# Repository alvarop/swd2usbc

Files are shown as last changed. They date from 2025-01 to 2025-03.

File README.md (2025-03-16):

# SWD2USBC Project

Have you ever wanted to debug your device over USB-C? Sometimes there's not enough room for a JTAG/SWD connector, or even [Tag-Connect](https://www.tag-connect.com/) pads!

For history and all of the details, check out [my detailed write up here](https://alvarop.com/2025/03/swd-to-usbc/).

## SWD2USBC
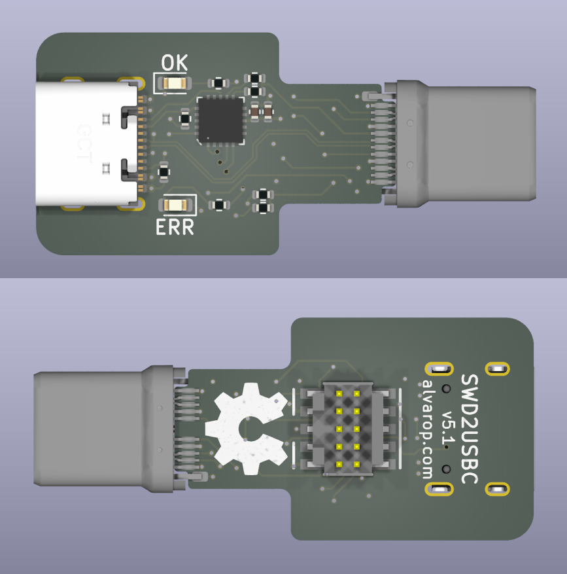
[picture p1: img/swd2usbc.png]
SWD2USBC
 

Full featured adapter with Debug Accessory Mode support. Includes an ATTiny microcontroller to set the correct pull-up resistors on CC1/CC2 to provide accurate charge current to the target. Has a USB-C plug so no extra USB-C cable required

### SWD2USBC Firmware
The ATTiny firmware doesn't do much. It reads the voltage on the CC1/CC2 line that is pulled up and determines the available charge current. It then pulls up CC1 **and** CC2 to provide the charge current to the device under Debug Accessory Mode.

## SWD2USBC Basic
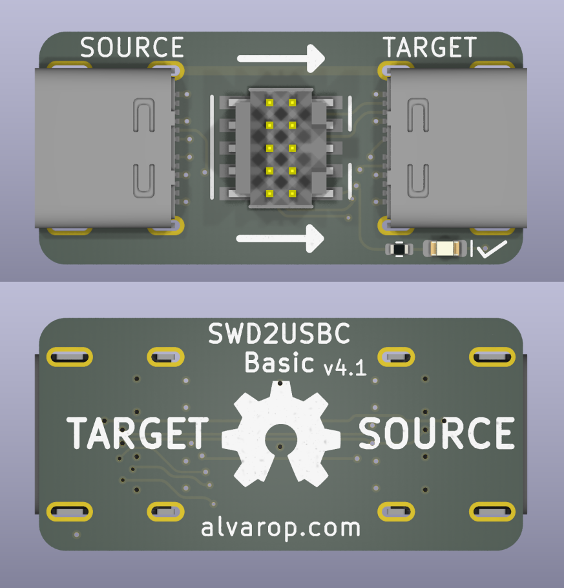
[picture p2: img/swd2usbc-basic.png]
SWD2USBC Basic
 
Simple adapter with no Debug Accessory Mode. Assumes target SWD lines wired up directly to TX1/2 as listed above. Requires USB3/Thunderbolt C to C cable to connect to target.

## Sample Target 
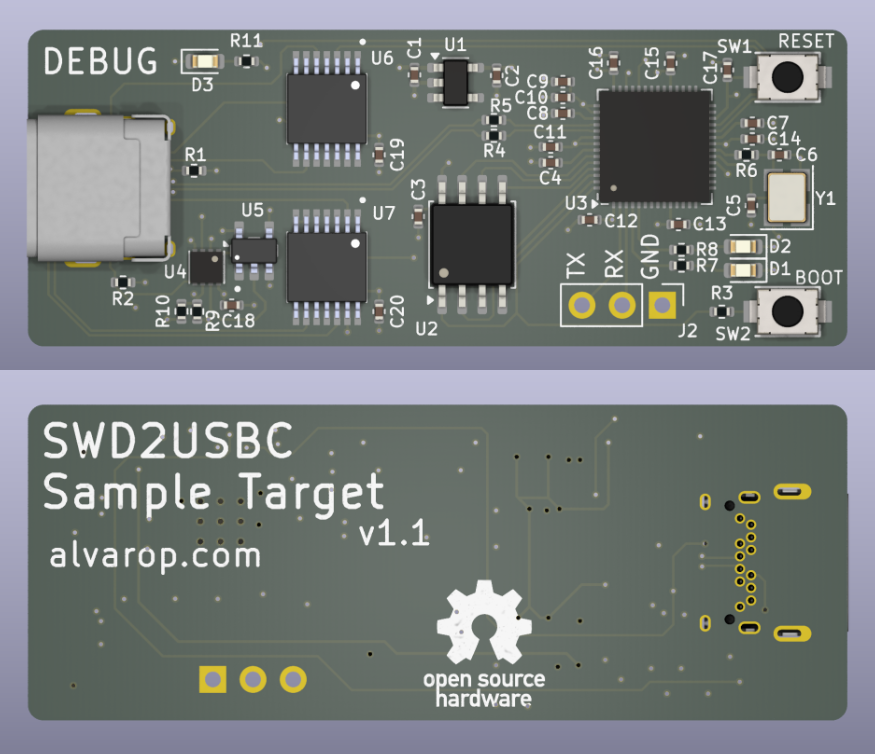
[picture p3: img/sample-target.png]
Sample Target
 

Example target device. Fully featured with CC1/2 comparators to connect/disconnect SWD lines if Debug Accessory Mode is active. Target is an RP2040 instead of STM32 since it's easier to source.

### Sample Target Firmware
The sample target firmware does basic USB charge detection using the CC lines. When the Debug Accessory Mode is enabled, both CC1/CC2 are used, otherwise, the single CC line is used. There's an LED (D3) which lights up when Debug Accessory Mode is enabled.

The charge current is printed out over UART, but it is also displayed using the two LEDs. The blink patterns are:
* **500mA** - LED1 (D1) blinks 
* **1500mA** - LED2 (D2) blinks 
* **3000mA** - Both LED1 (D1) and LED2 (D2) blink at the same time
* **Other/Error** - Both LED1 (D1) and LED2 (D2) alternating blink

## Sample Target Basic
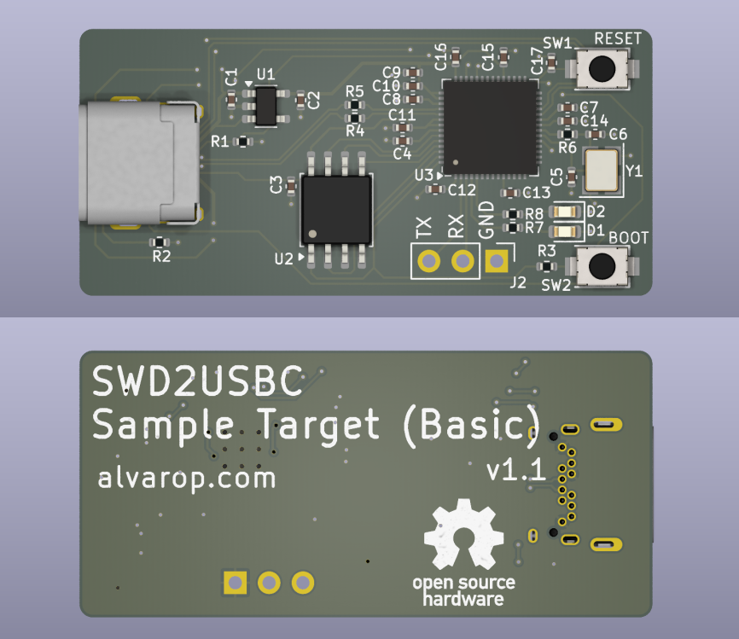
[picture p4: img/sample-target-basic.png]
Sample Target Basic
 

Basic example target. Similar to the sample target above, but does not include any comparators/switches. SWD lines are directly connected to the USB-C connector.

## SWD2USBC Programmer
Simple adapter PCB to connect the AVRISP V2 connector to USB-C to program the ATTiny in the SWD2USBC device.

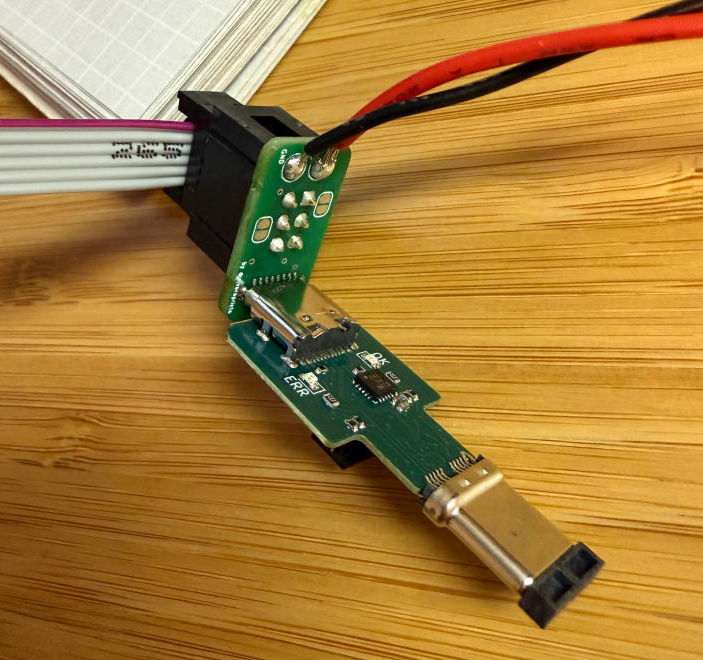
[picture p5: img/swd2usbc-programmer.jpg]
SWD2USBC Programmer


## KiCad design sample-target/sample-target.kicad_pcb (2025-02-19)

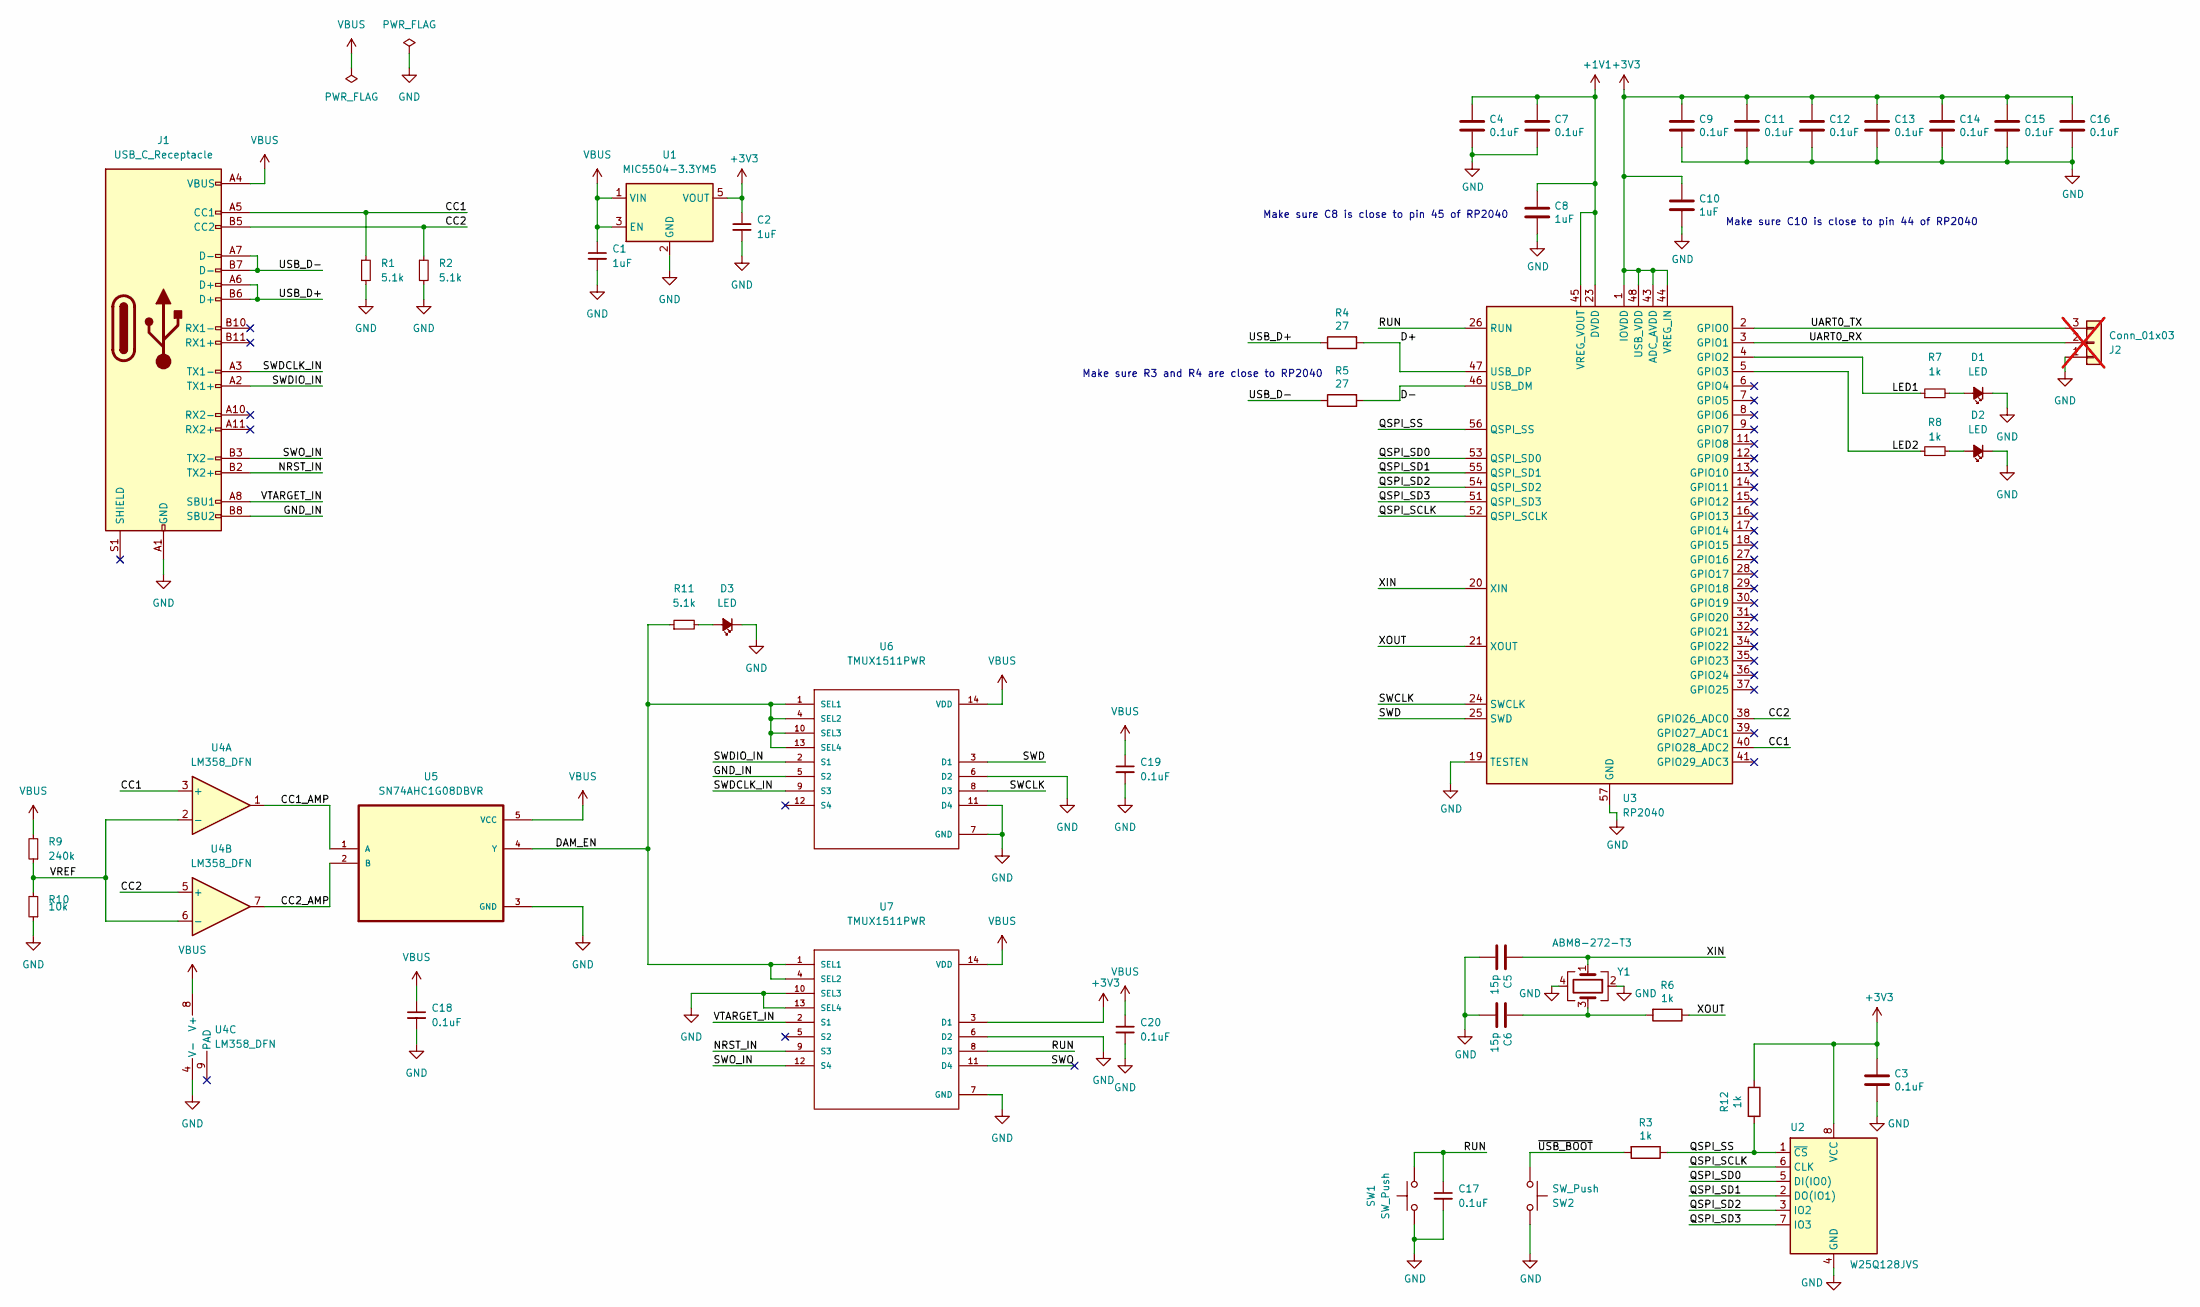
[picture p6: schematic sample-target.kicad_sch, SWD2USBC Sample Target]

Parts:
C1, C2, C8, C10: 1uF; C_0402_1005Metric; LCSC C52923
C3, C4, C7, C9, C11, C12, C13, C14, C15, C16, C17, C18, C19, C20: 0.1uF; C_0402_1005Metric; MPN CL05B104KB54PNC; LCSC C307331
C5, C6: 15p; C_0402_1005Metric; LCSC C106997
D1, D2, D3: LED; LED_0603_1608Metric; LCSC C72038
J1: USB_C_Receptacle; UT11113-11602-7H; MPN UT11113-11602-7H; LCSC C2761408
J2: Conn_01x03; PinHeader_1x03_P2.54mm_Vertical; not fitted
R1, R2, R11: 5.1k; R_0402_1005Metric; LCSC C105872
R3, R6, R7, R8, R12: 1k; R_0402_1005Metric; LCSC C4190
R4, R5: 27; R_0402_1005Metric; LCSC C137890
R9: 240k; R_0402_1005Metric; LCSC C138029
R10: 10k; R_0402_1005Metric; LCSC C25744
SW1, SW2: SW_Push; SW-SMD_L3.9-W3.0-P4.45; MPN SKRKAEE020; LCSC C115357
U1: MIC5504-3.3YM5; SOT-23-5; MPN MIC5504-3.3YM5-TR; LCSC C41348078
U2: W25Q128JVS; SOIC-8_5.23x5.23mm_P1.27mm; MPN W25Q128JVS; LCSC C97521
U3: RP2040; QFN-56-1EP_7x7mm_P0.4mm_EP3.2x3.2mm; MPN RP2040; LCSC C2040
U4: LM358_DFN; DFN-8-1EP_2x2mm_P0.5mm_EP1.05x1.75mm; MPN LM358QT; LCSC C2649392
U5: SN74AHC1G08DBVR; SOT95P280X145-5N; MPN SN74AHC1G08DBVR; LCSC C7467
U6, U7: TMUX1511PWR; SOP65P640X120-14N; MPN TMUX1511PWR; LCSC C2866750
Y1: ABM8-272-T3; Crystal_SMD_3225-4Pin_3.2x2.5mm; MPN ABM8-272-T3; LCSC C20625731

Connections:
+1V1: C4.1, C7.1, C8.1, U3.23 (DVDD), U3.45 (VREG_VOUT), U3.50 (DVDD)
+3V3: C2.1, C3.1, C9.1, C10.1, C11.1, C12.1, C13.1, C14.1, C15.1, C16.1, R12.1, U1.5 (VOUT), U2.8 (VCC), U3.1 (IOVDD), U3.10 (IOVDD), U3.22 (IOVDD), U3.33 (IOVDD), U3.42 (IOVDD), U3.43 (ADC_AVDD), U3.44 (VREG_IN), U3.48 (USB_VDD), U3.49 (IOVDD), U7.3 (D1)
/CC1: J1.A5 (CC1), R1.1, U3.40 (GPIO28_ADC2), U4.3 (+)
/CC1_AMP: U4.1, U5.1 (A)
/CC2: J1.B5 (CC2), R2.1, U3.38 (GPIO26_ADC0), U4.5 (+)
/CC2_AMP: U4.7, U5.2 (B)
/D+: R4.2, U3.47 (USB_DP)
/D-: R5.2, U3.46 (USB_DM)
/DAM_EN: R11.1, U5.4 (Y), U6.1 (SEL1), U6.4 (SEL2), U6.10 (SEL3), U6.13 (SEL4), U7.1 (SEL1), U7.4 (SEL2)
/GND_IN: J1.B8 (SBU2), U6.5 (S2)
/LED1: R7.1, U3.4 (GPIO2)
/LED2: R8.1, U3.5 (GPIO3)
/NRST_IN: J1.B2 (TX2+), U7.9 (S3)
/QSPI_SCLK: U2.6 (CLK), U3.52 (QSPI_SCLK)
/QSPI_SD0: U2.5 (DI(IO0)), U3.53 (QSPI_SD0)
/QSPI_SD1: U2.2 (DO(IO1)), U3.55 (QSPI_SD1)
/QSPI_SD2: U2.3 (IO2), U3.54 (QSPI_SD2)
/QSPI_SD3: U2.7 (IO3), U3.51 (QSPI_SD3)
/QSPI_SS: R3.1, R12.2, U2.1 (~CS), U3.56 (QSPI_SS)
/RUN: C17.1, SW1.2, U3.26 (RUN), U7.8 (D3)
/SWCLK: U3.24 (SWCLK), U6.8 (D3)
/SWD: U3.25 (SWD), U6.3 (D1)
/SWDCLK_IN: J1.A3 (TX1-), U6.9 (S3)
/SWDIO_IN: J1.A2 (TX1+), U6.2 (S1)
/SWO: U7.11 (D4)
/SWO_IN: J1.B3 (TX2-), U7.12 (S4)
/UART0_RX: J2.2, U3.3 (GPIO1)
/UART0_TX: J2.3, U3.2 (GPIO0)
/USB_D+: J1.A6 (D+), J1.B6 (D+), R4.1
/USB_D-: J1.A7 (D-), J1.B7 (D-), R5.1
/VREF: R9.1, R10.2, U4.2 (-), U4.6 (-)
/VTARGET_IN: J1.A8 (SBU1), U7.2 (S1)
/XIN: C5.1, U3.20 (XIN), Y1.1
/XOUT: R6.1, U3.21 (XOUT)
/~USB_BOOT: R3.2, SW2.2
GND: C1.2, C2.2, C3.2, C4.2, C5.2, C6.2, C7.2, C8.2, C9.2, C10.2, C11.2, C12.2, C13.2, C14.2, C15.2, C16.2, C17.2, C18.2, C19.2, C20.2, D1.1 (K), D2.1 (K), D3.1 (K), J1.A1 (GND), J1.A12 (GND), J1.B1 (GND), J1.B12 (GND), J2.1, R1.2, R2.2, R10.1, SW1.1, SW2.1, U1.2 (GND), U2.4 (GND), U3.19 (TESTEN), U3.57 (GND), U4.4 (V-), U5.3 (GND), U6.6 (D2), U6.7 (GND), U6.11 (D4), U7.6 (D2), U7.7 (GND), U7.10 (SEL3), U7.13 (SEL4), Y1.2, Y1.4
unnamed: C6.1, R6.2, Y1.3
unnamed: D1.2 (A), R7.2
unnamed: D2.2 (A), R8.2
unnamed: D3.2 (A), R11.2
VBUS: C1.1, C18.1, C19.1, C20.1, J1.A4 (VBUS), J1.A9 (VBUS), J1.B4 (VBUS), J1.B9 (VBUS), R9.2, U1.1 (VIN), U1.3 (EN), U4.8 (V+), U5.5 (VCC), U6.14 (VDD), U7.14 (VDD)

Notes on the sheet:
Make sure C10 is close to pin 44 of RP2040
Make sure C8 is close to pin 45 of RP2040
Make sure R3 and R4 are close to RP2040

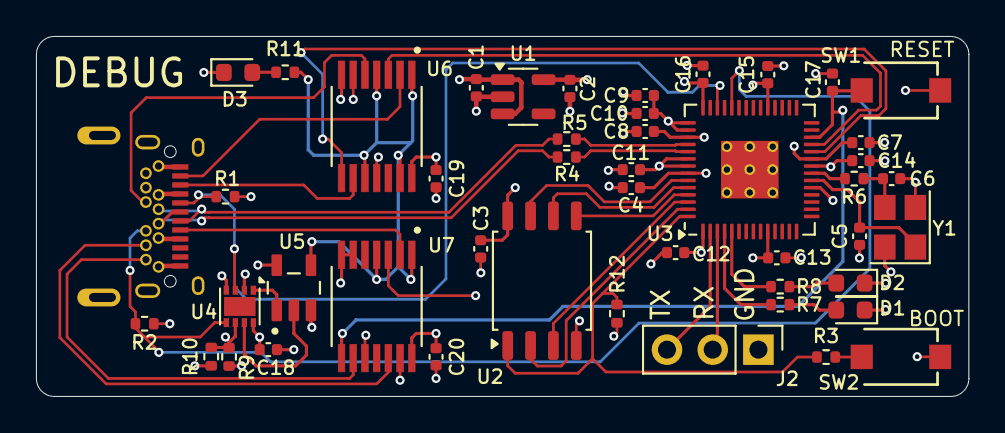
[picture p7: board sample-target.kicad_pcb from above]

Board: 4 copper layers, 51.8 x 20.0 mm, 47 parts (0 on the bottom side), 40 nets.

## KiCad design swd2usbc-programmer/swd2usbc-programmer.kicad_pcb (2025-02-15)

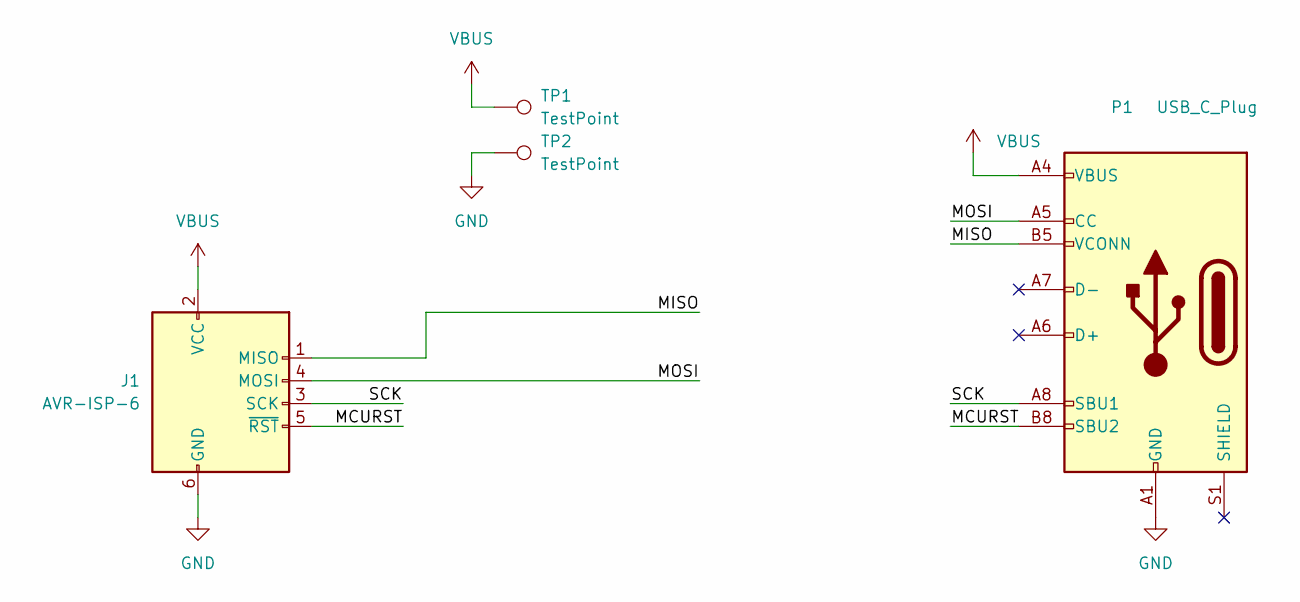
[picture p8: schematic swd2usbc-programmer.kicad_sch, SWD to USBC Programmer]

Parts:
J1: AVR-ISP-6; IDC-Header_2x03_P2.54mm_Vertical; MPN 30306-6002HB
P1: USB_C_Plug; TYPE-C-31-G-06; MPN TYPE-C-31-G-06
TP1, TP2: TestPoint; TestPoint_Pad_D2.5mm

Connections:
/MCURST: J1.5 (~RST), P1.B8 (SBU2)
/MISO: J1.1 (MISO), P1.B5 (VCONN)
/MOSI: J1.4 (MOSI), P1.A5 (CC)
/SCK: J1.3 (SCK), P1.A8 (SBU1)
GND: J1.6 (GND), P1.A1 (GND), P1.A12 (GND), P1.B1 (GND), P1.B12 (GND), TP2.1
VBUS: J1.2 (VCC), P1.A4 (VBUS), P1.A9 (VBUS), P1.B4 (VBUS), P1.B9 (VBUS), TP1.1

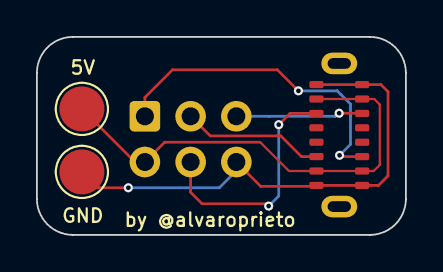
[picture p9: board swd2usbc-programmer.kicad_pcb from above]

Board: 2 copper layers, 20.5 x 11.0 mm, 4 parts (1 on the bottom side), 6 nets.

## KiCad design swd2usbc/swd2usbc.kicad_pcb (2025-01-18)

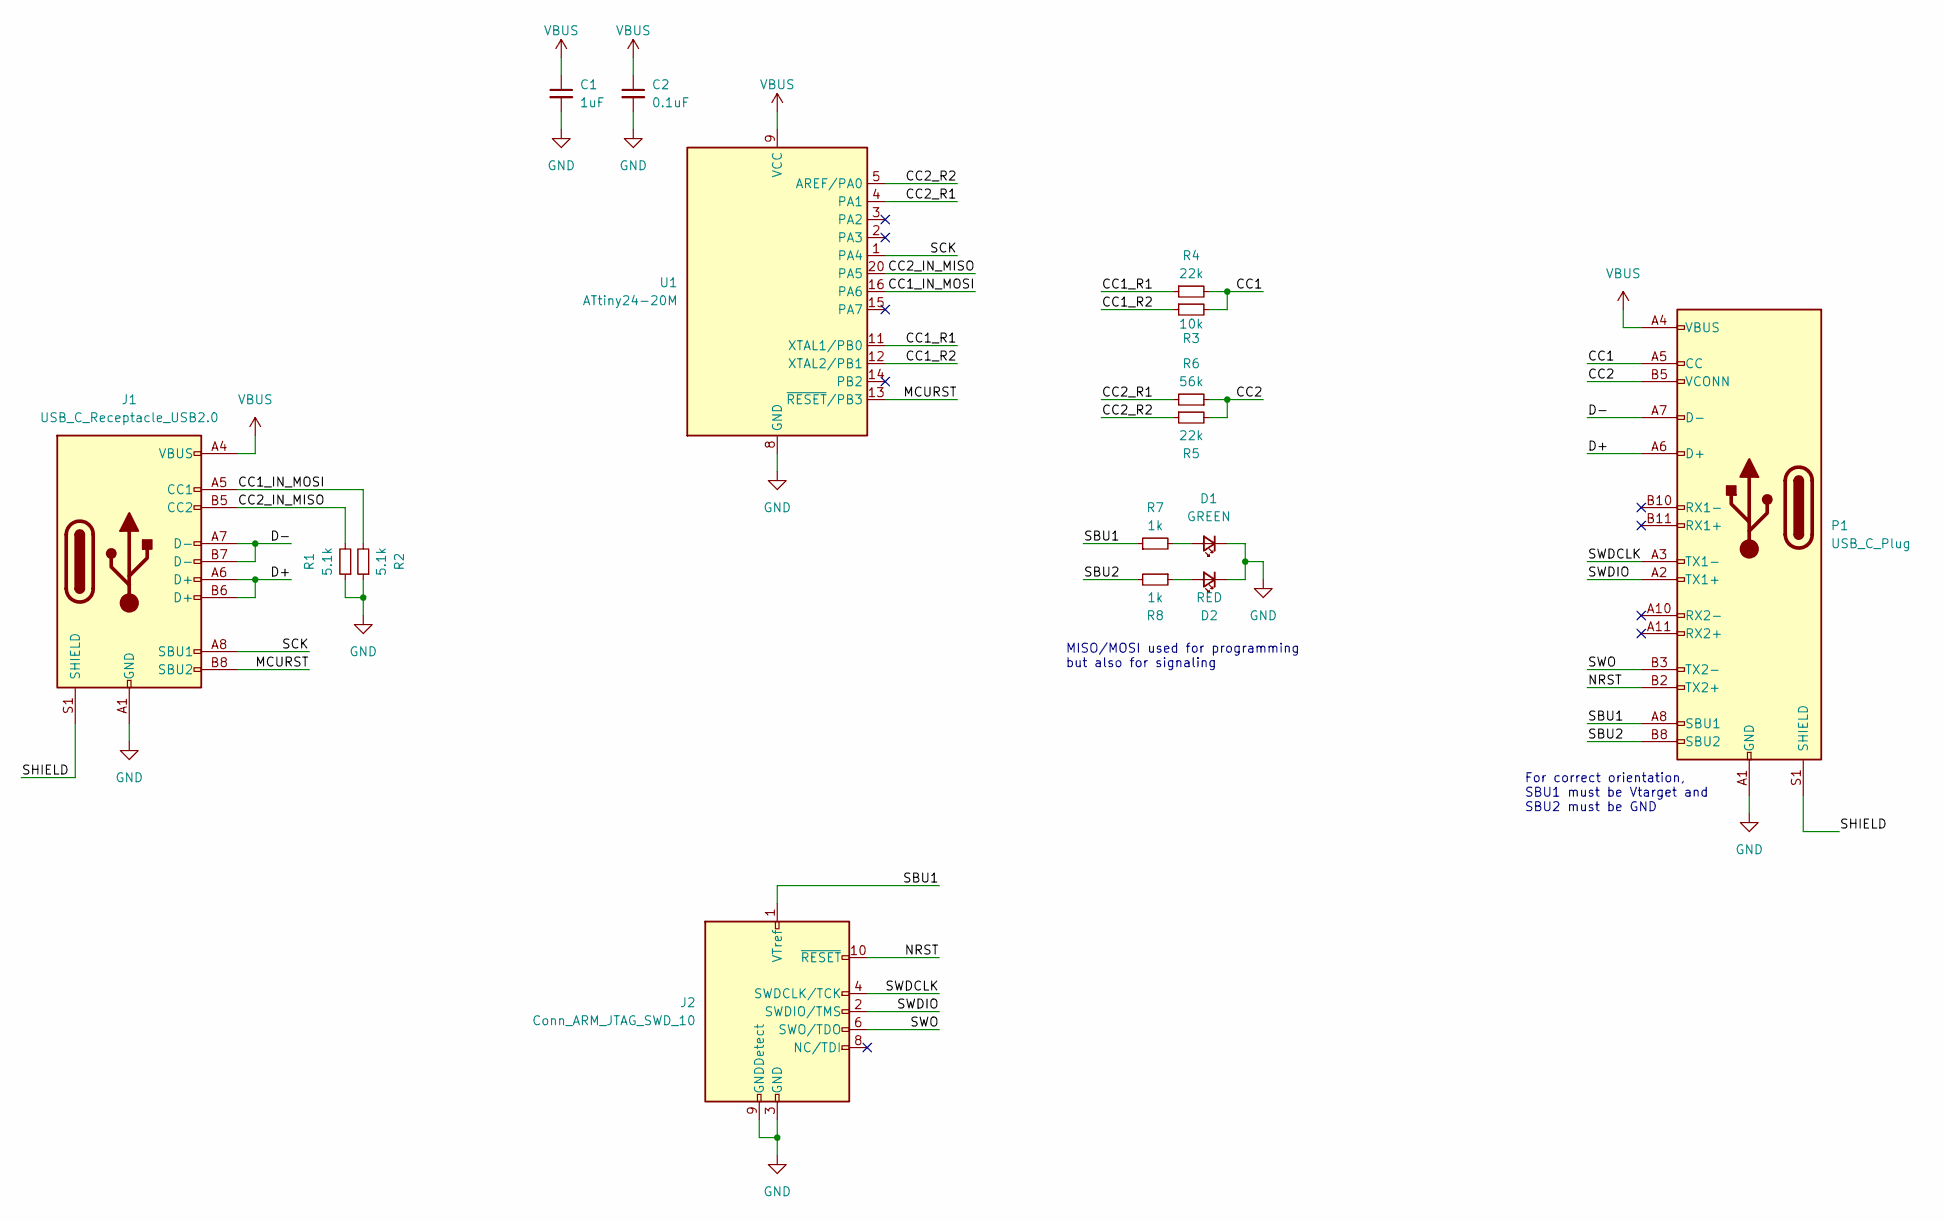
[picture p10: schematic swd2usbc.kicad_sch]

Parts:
C1: 1uF; C_0402_1005Metric; MPN CL05A105KO5NNNC; LCSC C52923
C2: 0.1uF; C_0402_1005Metric; MPN CL05B104KO5NNNC; LCSC C307331
D1: GREEN; LED_0603_1608Metric; MPN SML-D12M8WT86; LCSC C965804
D2: RED; LED_0603_1608Metric; MPN SML-D12U1WT86; LCSC C2286
J1: USB_C_Receptacle_USB2.0; USB4105-GF-A; MPN USB4105-GF-A; LCSC C136423
J2: Conn_ARM_JTAG_SWD_10; SAMTEC_FTSH-105-01-F-DV-P-TR; MPN FTSH-105-01-F-DV-K; LCSC C2935458
P1: USB_C_Plug; MOLEX_1054440011; MPN 1054440011; LCSC C561769
R1, R2: 5.1k; R_0402_1005Metric; MPN RC0402FR-075K1L; LCSC C105872
R3: 10k; R_0402_1005Metric; MPN RC0402FR-0710KL; LCSC C25744
R4, R5: 22k; R_0402_1005Metric; MPN RC0402FR-0722KL; LCSC C25768
R6: 56k; R_0402_1005Metric; MPN RC0402FR-0756KL; LCSC C25796
R7, R8: 1k; R_0402_1005Metric; MPN RC0402FR-071KL; LCSC C4190
U1: ATtiny24-20M; ATTINY24A-MMH; MPN ATTINY24A-MMH; LCSC C617902

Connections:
/CC1: P1.A5 (CC), R3.2, R4.2
/CC1_IN_MOSI: J1.A5 (CC1), R2.2, U1.16 (PA6)
/CC1_R1: R4.1, U1.11 (XTAL1/PB0)
/CC1_R2: R3.1, U1.12 (XTAL2/PB1)
/CC2: P1.B5 (VCONN), R5.2, R6.1
/CC2_IN_MISO: J1.B5 (CC2), R1.2, U1.20 (PA5)
/CC2_R1: R6.2, U1.4 (PA1)
/CC2_R2: R5.1, U1.5 (AREF/PA0)
/D+: J1.A6 (D+), J1.B6 (D+), P1.A6 (D+)
/D-: J1.A7 (D-), J1.B7 (D-), P1.A7 (D-)
/MCURST: J1.B8 (SBU2), U1.13 (~RESET/PB3)
/NRST: J2.10 (~RESET), P1.B2 (TX2+)
/SBU1: J2.1 (VTref), P1.A8 (SBU1), R7.1
/SBU2: P1.B8 (SBU2), R8.2
/SCK: J1.A8 (SBU1), U1.1 (PA4)
/SHIELD: J1.S1 (SHIELD), P1.S1 (SHIELD)
/SWDCLK: J2.4 (SWDCLK/TCK), P1.A3 (TX1-)
/SWDIO: J2.2 (SWDIO/TMS), P1.A2 (TX1+)
/SWO: J2.6 (SWO/TDO), P1.B3 (TX2-)
GND: C1.2, C2.2, D1.1 (K), D2.1 (K), J1.A1 (GND), J1.A12 (GND), J1.B1 (GND), J1.B12 (GND), J2.3 (GND), J2.5 (GND), J2.9 (GNDDetect), P1.A1 (GND), P1.A12 (GND), P1.B1 (GND), P1.B12 (GND), R1.1, R2.1, U1.8 (GND), U1.21 (GND)
unnamed: D1.2 (A), R7.2
unnamed: D2.2 (A), R8.1
VBUS: C1.1, C2.1, J1.A4 (VBUS), J1.A9 (VBUS), J1.B4 (VBUS), J1.B9 (VBUS), P1.A4 (VBUS), P1.A9 (VBUS), P1.B4 (VBUS), P1.B9 (VBUS), U1.9 (VCC)

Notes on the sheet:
MISO/MOSI used for programming but also for signaling
For correct orientation, SBU1 must be Vtarget and SBU2 must be GND

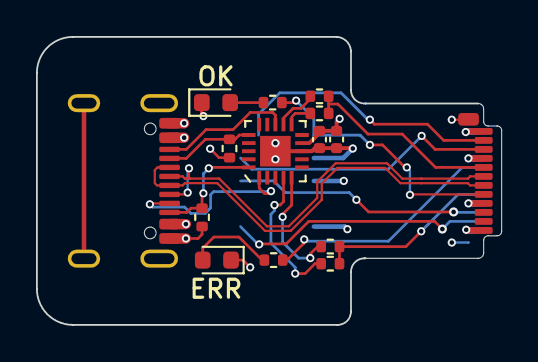
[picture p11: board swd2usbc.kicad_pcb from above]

Board: 4 copper layers, 25.8 x 16.0 mm, 16 parts (1 on the bottom side), 23 nets.

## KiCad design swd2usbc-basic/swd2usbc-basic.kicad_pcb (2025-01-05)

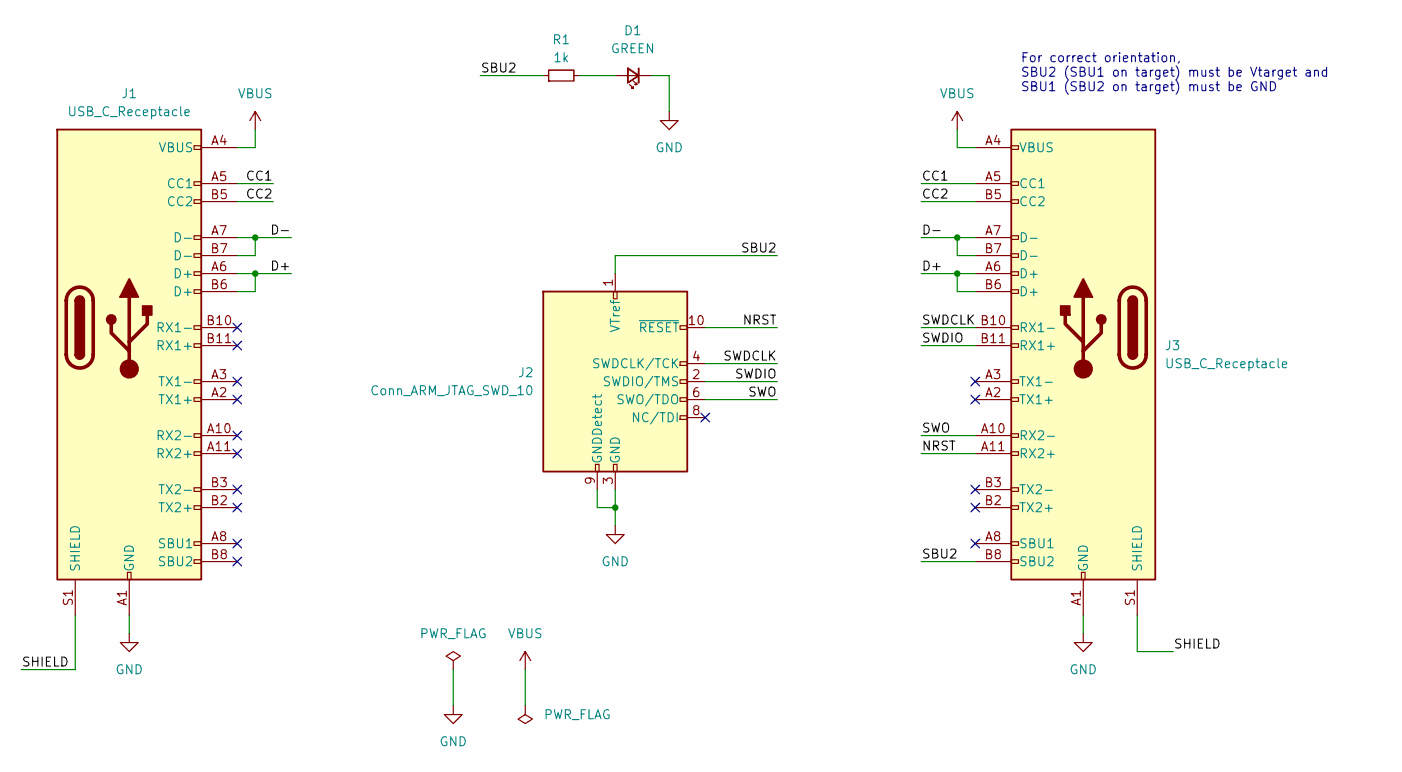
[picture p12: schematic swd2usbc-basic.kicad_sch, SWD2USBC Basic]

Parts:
D1: GREEN; LED_0603_1608Metric; MPN SML-D12M8WT86; LCSC C965804
J1, J3: USB_C_Receptacle; MOLEX-1054500101; MPN 1054500101; LCSC C134092
J2: Conn_ARM_JTAG_SWD_10; SAMTEC_FTSH-105-01-F-DV-P-TR; MPN FTSH-105-01-F-DV-K-P-TR; LCSC C19191729
R1: 1k; R_0402_1005Metric; MPN RC0402FR-071KL; LCSC C25744

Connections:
/CC1: J1.A5 (CC1), J3.A5 (CC1)
/CC2: J1.B5 (CC2), J3.B5 (CC2)
/D+: J1.A6 (D+), J1.B6 (D+), J3.A6 (D+), J3.B6 (D+)
/D-: J1.A7 (D-), J1.B7 (D-), J3.A7 (D-), J3.B7 (D-)
/NRST: J2.10 (~RESET), J3.A11 (RX2+)
/SBU2: J2.1 (VTref), J3.B8 (SBU2), R1.1
/SHIELD: J1.S1 (SHIELD), J3.S1 (SHIELD)
/SWDCLK: J2.4 (SWDCLK/TCK), J3.B10 (RX1-)
/SWDIO: J2.2 (SWDIO/TMS), J3.B11 (RX1+)
/SWO: J2.6 (SWO/TDO), J3.A10 (RX2-)
GND: D1.1 (K), J1.A1 (GND), J1.A12 (GND), J1.B1 (GND), J1.B12 (GND), J2.3 (GND), J2.5 (GND), J2.9 (GNDDetect), J3.A1 (GND), J3.A12 (GND), J3.B1 (GND), J3.B12 (GND)
unnamed: D1.2 (A), R1.2
VBUS: J1.A4 (VBUS), J1.A9 (VBUS), J1.B4 (VBUS), J1.B9 (VBUS), J3.A4 (VBUS), J3.A9 (VBUS), J3.B4 (VBUS), J3.B9 (VBUS)

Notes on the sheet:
For correct orientation, SBU2 (SBU1 on target) must be Vtarget and SBU1 (SBU2 on target) must be GND

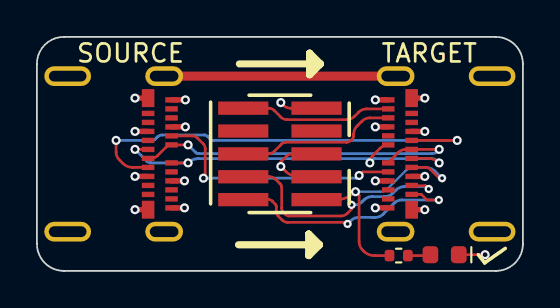
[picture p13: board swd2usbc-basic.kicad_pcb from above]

Board: 4 copper layers, 27.0 x 13.0 mm, 5 parts (0 on the bottom side), 13 nets.

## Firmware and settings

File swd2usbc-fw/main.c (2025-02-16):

#include <avr/io.h>
#include <util/delay.h>

#define MAX(X, Y) ((X) > (Y) ? (X) : (Y))

// Input CC1/CC2
#define CC1 PA6
#define CC2 PA5

// Output CC1/CC2 Rpu's
#define CC1_R2 PB1  // 10 kOhm
#define CC1_R1 PB0  // 22 kOhm
#define CC2_R2 PA0  // 22 kOhm
#define CC2_R1 PA1  // 56 kOhm

typedef enum {
  USB_500MA,
  USB_1500MA,
  USB_3000MA,
} USBCurrent_t;

// Current | CC1/CC2 In | CC1 Rpu          | CC2 Rpu
// 500mA   |    0.42V   | 10 kOhm (CC1_R2) | 22 kOhm (CC2_R2)
// 1.5A    |    0.94V   | 22 kOhm (CC1_R1) | 56 kOhm (CC2_R1)
// 3.0A    |    1.69V   | 10 kOhm (CC1_R2) | 56 kOhm (CC2_R1)

void set_usb_current(USBCurrent_t current) {
  switch (current) {
    case USB_500MA: {
      DDRB &= ~_BV(CC1_R1);
      DDRB |= _BV(CC1_R2);
      PORTB &= ~_BV(CC1_R1);
      PORTB |= _BV(CC1_R2);

      DDRA &= ~_BV(CC2_R1);
      DDRA |= _BV(CC2_R2);
      PORTA &= ~_BV(CC2_R1);
      PORTA |= _BV(CC2_R2);
      break;
    }
    case USB_1500MA: {
      DDRB &= ~_BV(CC1_R2);
      DDRB |= _BV(CC1_R1);
      PORTB &= ~_BV(CC1_R2);
      PORTB |= _BV(CC1_R1);

      DDRA &= ~_BV(CC2_R2);
      DDRA |= _BV(CC2_R1);
      PORTA &= ~_BV(CC2_R2);
      PORTA |= _BV(CC2_R1);
      break;
    }
    case USB_3000MA: {
      DDRB &= ~_BV(CC1_R1);
      DDRB |= _BV(CC1_R2);
      PORTB &= ~_BV(CC1_R1);
      PORTB |= _BV(CC1_R2);

      DDRA &= ~_BV(CC2_R2);
      DDRA |= _BV(CC2_R1);
      PORTA &= ~_BV(CC2_R2);
      PORTA |= _BV(CC2_R1);
      break;
    }
  }
}

uint16_t adc_sample_mv(uint8_t channel) {
  ADMUX = channel;
  ADCSRA |= (1 << ADSC);  // Start conversion

  // Wait for conversion to complete
  while (ADCSRA & (1 << ADSC));

  uint16_t raw_adc_val = ADC;
  uint32_t adc_mv = ((uint32_t)raw_adc_val * 5000) / 1024;

  return adc_mv;
}

// CC1/CC2 voltages for various USB C currents
#define USB_CC_MV_500MA 200
#define USB_CC_MV_1500MA 660
#define USB_CC_MV_3000MA 1230

USBCurrent_t get_cc_current(void) {
  // Read CC1/CC2 values for input current detection
  uint16_t cc1 = adc_sample_mv(CC1);
  uint16_t cc2 = adc_sample_mv(CC2);

  cc1 = MAX(cc1, cc2);

  USBCurrent_t curent;
  if (cc1 <= USB_CC_MV_1500MA) {
    curent = USB_500MA;
  } else if (cc1 <= USB_CC_MV_3000MA) {
    curent = USB_1500MA;
  } else {
    curent = USB_3000MA;
  }

  return curent;
}

int main(void) {
  // Set port B output 0 as inputs
  DDRA &= ~(_BV(CC2_R2) | _BV(CC2_R1));
  DDRB &= ~(_BV(CC1_R2) | _BV(CC1_R1));

  // Set outputs high (so they are on when switched to outputs)
  PORTA = _BV(CC2_R2) | _BV(CC2_R1);
  PORTB = _BV(CC1_R2) | _BV(CC1_R1);

  // ADC Enable with / 16 prescaler (62.5kHz)
  ADCSRA = (1 << ADEN) | 3;

  // Disable digital inputs on ADC pins
  DIDR0 |= _BV(CC1) | _BV(CC2);

  // Default to 500mA charge current to start
  set_usb_current(USB_500MA);

  while (1) {
    set_usb_current(get_cc_current());
    _delay_ms(10);
  }
  return 0;
}

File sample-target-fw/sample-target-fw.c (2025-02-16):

#include <stdio.h>

#include "hardware/adc.h"
#include "hardware/gpio.h"
#include "pico/stdlib.h"
#define LED1 (2)
#define LED2 (3)

float read_adc_v(uint8_t adc_ch) {
  const float conversion_factor = 3.3f / (1 << 12);
  adc_select_input(adc_ch);
  return (float)adc_read() * conversion_factor;
}

// Defines for voltage at each CCx charge level in normal mode
// Debug Accessory Mode uses same voltage levels but they mean different things
// USB-C Spec R2.0 - Tables 4-24 and 4-36
#define USB_CC_500MA_V 0.2
#define USB_CC_1500MA_V 0.66
#define USB_CC_3000MA_V 1.23

#define CC1_ADC_CH (2)
#define CC2_ADC_CH (0)

static uint32_t get_charge_current(bool *in_debug_mode) {
  uint32_t charge_current_ma = 0;

  float cc1 = read_adc_v(CC1_ADC_CH);
  float cc2 = read_adc_v(CC2_ADC_CH);

  // Make sure this works in both orientations
  float USB_cc_max = MAX(cc1, cc2);
  float USB_cc_min = MIN(cc1, cc2);

  // Both cc1 AND cc2 are high, use Debug Accessory Mode decoding
  // USB-C spec R2.0 Table B-2 and Table 4-36
  if ((USB_cc_max > USB_CC_500MA_V) && (USB_cc_min > USB_CC_500MA_V)) {
    if ((USB_cc_max >= USB_CC_3000MA_V) && (USB_cc_min <= USB_CC_3000MA_V) &&
        (USB_cc_min >= USB_CC_1500MA_V)) {
      charge_current_ma = 500;
    } else if ((USB_cc_max <= USB_CC_3000MA_V) &&
               (USB_cc_max >= USB_CC_1500MA_V) &&
               (USB_cc_min <= USB_CC_1500MA_V)) {
      charge_current_ma = 1500;
    } else if ((USB_cc_max >= USB_CC_3000MA_V) &&
               (USB_cc_min <= USB_CC_1500MA_V)) {
      charge_current_ma = 3000;
    } else {
      charge_current_ma = 0;
    }
    if (in_debug_mode) {
      *in_debug_mode = true;
    }
  } else {
    // Normal charge current detection
    float USB_cc_max = MAX(cc1, cc2);

    // USB-C spec R2.0 Table 4-36
    if (USB_cc_max <= USB_CC_500MA_V) {
      charge_current_ma = 0;
    } else if (USB_cc_max <= USB_CC_1500MA_V) {
      charge_current_ma = 500;
    } else if (USB_cc_max <= USB_CC_3000MA_V) {
      charge_current_ma = 1500;
    } else {
      charge_current_ma = 3000;
    }

    if (in_debug_mode) {
      *in_debug_mode = false;
    }
  }

  if (charge_current_ma == 0) {
    printf("Unknown charge current CC1: %0.2fV CC2: %0.2fV\n", cc1, cc2);
  }

  return charge_current_ma;
}

int main() {
  stdio_init_all();

  // Initialize LEDs
  gpio_init(LED1);
  gpio_init(LED2);
  gpio_set_dir(LED1, GPIO_OUT);
  gpio_set_dir(LED2, GPIO_OUT);

  // Initialize ADC and ADC pins
  adc_init();
  adc_gpio_init(26);
  adc_gpio_init(28);

  uint8_t count = 0;
  while (true) {
    bool in_debug_mode;
    uint32_t charge_current_ma = get_charge_current(&in_debug_mode);

    printf("Charge current: %lumA (Debug Accessory Mode = %d)\n",
           charge_current_ma, in_debug_mode);

    // Change blink pattern according to charge current
    switch (charge_current_ma) {
      case 500: {
        // 500mA blink LED1
        gpio_put(LED1, (count & 1));
        gpio_put(LED2, 0);
        break;
      }

      case 1500: {
        // 1500mA blink LED2
        gpio_put(LED1, 0);
        gpio_put(LED2, (count & 1));
        break;
      }

      case 3000: {
        // 3000mA blink both LEDs
        gpio_put(LED1, (count & 1));
        gpio_put(LED2, (count & 1));
        break;
      }

      default: {
        // Error/unknown - alternating blinks
        gpio_put(LED1, (count & 1));
        gpio_put(LED2, !(count & 1));
      }
    }

    sleep_ms(500);
    count++;
  }
}

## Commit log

2024-12-31 Initial commit of v4.1 basic
    [swd2usb-basic.kicad_pcb, swd2usb-basic.kicad_sch]
2025-01-05 Add sample targets
    [sample-target-basic.kicad_pcb, sample-target-basic.kicad_sch, sample-target.kicad_pcb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]
2025-01-05 Adding swd2usbc and renaming swd2usbc-basic
    [swd2usb-basic.kicad_pcb, swd2usbc-basic.kicad_pcb, swd2usbc-basic.kicad_sch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]
2025-01-05 Various fixes while ordering from JLCPCB
    [sample-target-basic.kicad_pcb, sample-target-basic.kicad_sch, sample-target.kicad_pcb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]
2025-01-18 Should have checked my footprints...
    USB-C plug footprint was incorrect. I had fixed it in the library but forgot to update it in the project.........
    [swd2usbc.kicad_pcb, swd2usbc.kicad_sch]
2025-01-18 Fixed some silkscreen and added OSWH logo
    [swd2usbc.kicad_pcb]
2025-02-15 Add programmer PCB
    [swd2usbc-programmer.kicad_pcb, swd2usbc-programmer.kicad_sch]
2025-02-16 Add CC lines to sample targets
    [sample-target-basic.kicad_pcb, sample-target-basic.kicad_sch, sample-target.kicad_pcb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]
2025-02-16 Add sample target firmware
2025-02-19 Add pull up resistor to spi flash
    [sample-target-basic.kicad_pcb, sample-target-basic.kicad_sch, sample-target.kicad_pcb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]

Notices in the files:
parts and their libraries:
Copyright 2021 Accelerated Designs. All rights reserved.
